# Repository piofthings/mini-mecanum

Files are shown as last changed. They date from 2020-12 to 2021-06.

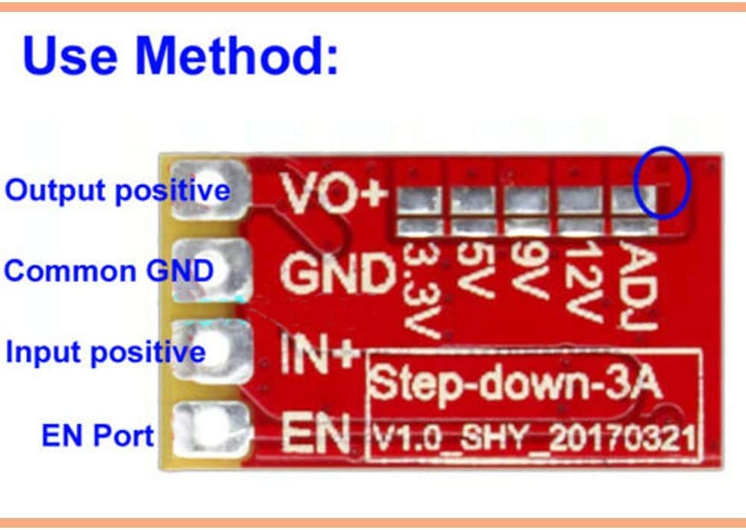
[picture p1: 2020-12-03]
references/powersupply/back-side.jpg

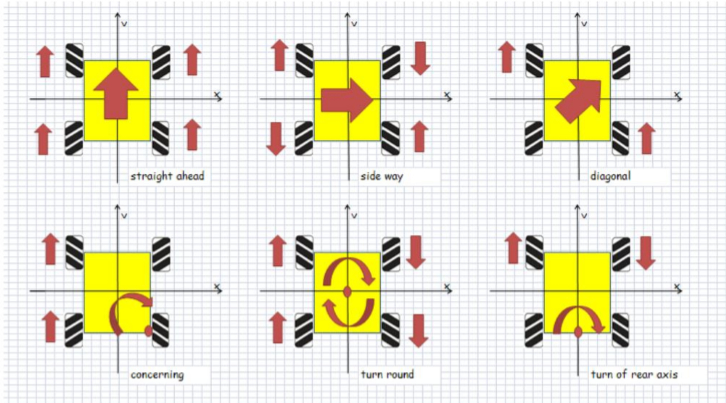
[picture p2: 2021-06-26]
references/mecanum-wheels-direction.jpeg

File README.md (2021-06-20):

# mini-mecanum

Mini Mecanum bot goes to [PiWars at Home 2021](https://piwars.org)

Yes, we couldn't resist and put our names in for [PiWars at Home 2021](https://piwars.org) and now we are in deep trouble.

# Motor Driver using GPIOZero
We are using 2xMDD3A Cytron motor drivers to drive 4 motors independently so we can strafe when we use Mecanum motors. The drivers use PWM signal for forward and backward directions instead of using a PWM and Direction pin.

Looks like the `GPIO Zero` libraries' `Motor` abstraction will work with this driver. So we are using the following Pins on the Pi

| # | Pin | Used | | Wire colour |
| :--- | --- | :--- | :--- | :--- |
| 1. | GPIO 17 (Physical 11) | Left Front | Forward  | Yellow |
| 2. | GPIO 27 (Physical 13) | Left Front | Backward | Blue |
| 3. | GPIO 23 (Phyiscal 16) | Left Rear | Forward  | Yellow |
| 4. | GPIO 24 (Physical 18) | Left Rear | Backward | Blue |
| 5. | GPIO 5 (Phyiscal 29)  | Right Front | Forward  | Yellow |
| 6. | GPIO 6 (Physical 31)  | Right Front | Backward | Blue |
| 7. | GPIO 26 (Phyiscal 37) | Right Rear | Forward  | Yellow |
| 8. | GPIO 16 (Phyiscal 36) | Right Rear | Backward | Blue |
| 9. | GPIO 2 (Physical 3) | I2C SDA | | |
| 10.  | GPIO 3 (Physical 5) | I2C SCL | | |
| 11.  | GPIO 22 (Physical 15) | S (Fish feeder Servo) | | |
| 13.  | Ground (Physical 06)  | UART | | |
| 14.  | GPIO 14 (Physical 08) | UART TX | | |
| 15.  | GPIO 16 (Physical 10) | UART RX | | |
| 16.  | 3v3 (Physical 1) | I2C/UART | | |
| 17.  | 5v (Physical 2) | | | |
| 18.  | GPIO 21 (Physical 40) | Blue Gripper Stop switch  | | |
| 19.  | GPIO 20 (Physical 39) | Red Gripper Stop switch | | |
| 20.  | GPIO 12 (Physical 32) | Green Gripper Stop switch | | |
  
## Used [*] / Unsed [_] (GPIO pins)

| | | | |
| :--- | --- | --- | --- |
| 3v3 Power | 01 [*] | [*] 02 | 5v Power /1 |
| GPIO 2(I2C SDA) | 03 [*] | [_] 04 | 5v Power |
| GPIO 2(I2C SDA) | 05 [*] | [*] 06 | Ground |
| GPIO 4(GPCLK0) | 07 [_] | [*] 08 | GPIO 14 (UART TX) |
| Ground | 09 [_] | [*] 10 | GPIO 15 (UART RX) |
| GPIO 17 | 11 [*] | [_] 12 | GPIO 18 (PCM CLK) |
| GPIO 27 | 13 [*] | [*] 14 | Ground |
| GPIO 22 | 15 [_] | [*] 16 | GPIO 23 |
| 3v3 Power | 17 [_] | [*] 18 | GPIO 24 |
| GPIO 10 (SPI MOSI)  | 19 [_] | [_] 20 | Ground |
| GPIO 9 (SPIO MISO)  | 21 [_] | [_] 22 | GPIO 25 |
| GPIO 11 (SPIO SCLK) | 23 [_] | [*] 24 | GPIO 8 (SPI0 CE0) |
| Ground | 25 [_] | [*] 26 | GPIO 7 (SPI0 CE1) |
| GPIO 0 (EEPROM SDA) | 27 [_] | [*] 28 | GPIO 1 (EEPROM SCL)) |
| GPIO 5 | 29 [*] | [_] 30 | Ground |
| GPIO 6 | 31 [*] | [*] 32 | GPIO 12 (PWM0) |
| GPIO 13 (PWM 1) | 33 [_] | [_] 34 | Ground |
| GPIO 19 (PCM FS) | 35 [_] | [*] 36 | GPIO 16 |
| GPIO 26 | 37 [*] | [*] 38 | GPIO 20 (PCM DIN) |
| Ground 39 | 39 [*] | [*] 40 | GPIO 21 (PCM DOUT) |

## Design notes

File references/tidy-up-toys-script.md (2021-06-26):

#Tidy up toys script

##Starting position
- All at lower most position but staggered Blue and Green lower than Red 
- Arm pinched `p` (angle 0) 
- Shoulders open `j`
- Go Back `s`
- Spin Clockwise `y` until corrected
- Stop `0`
- Go Forward Diagonal right `e`
- Go forward `w`
- Stop

##Grab Blue
- Select Blue `b`
- Release Hand `o`
- Grab hand `l`
- Spin Anticlockwise to face Red `t`
- Forward `w`

##Grab Red
- Select Red `r`
- Release Hand `o` (should swing over Green and Blue)
- Grab Hand  `l`
- Raise Hand `'` (for x seconds, figure out how much is x)
- Strafe right slightly `d` to line up with green
- Go forward `w`

##Grab Green
- Select Green `g`
- Release Hand `o`
- Grab hand    `l`
- Swing In     `h`
- Raise Hand `'` 
(for y seconds, figure out how much is y)
- Strafe left `a`

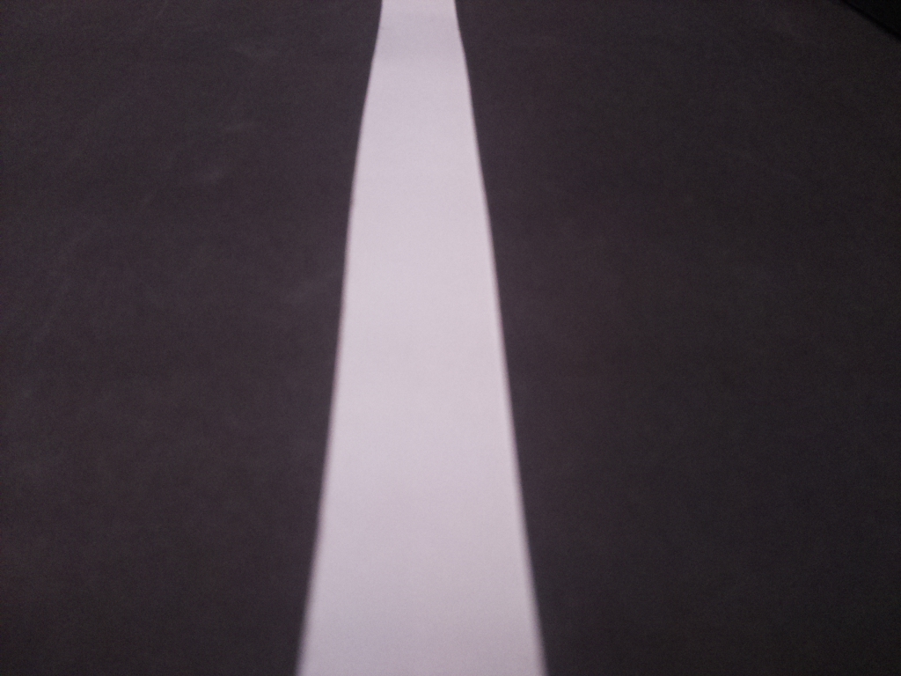
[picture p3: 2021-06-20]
dev/pi/foo.jpg

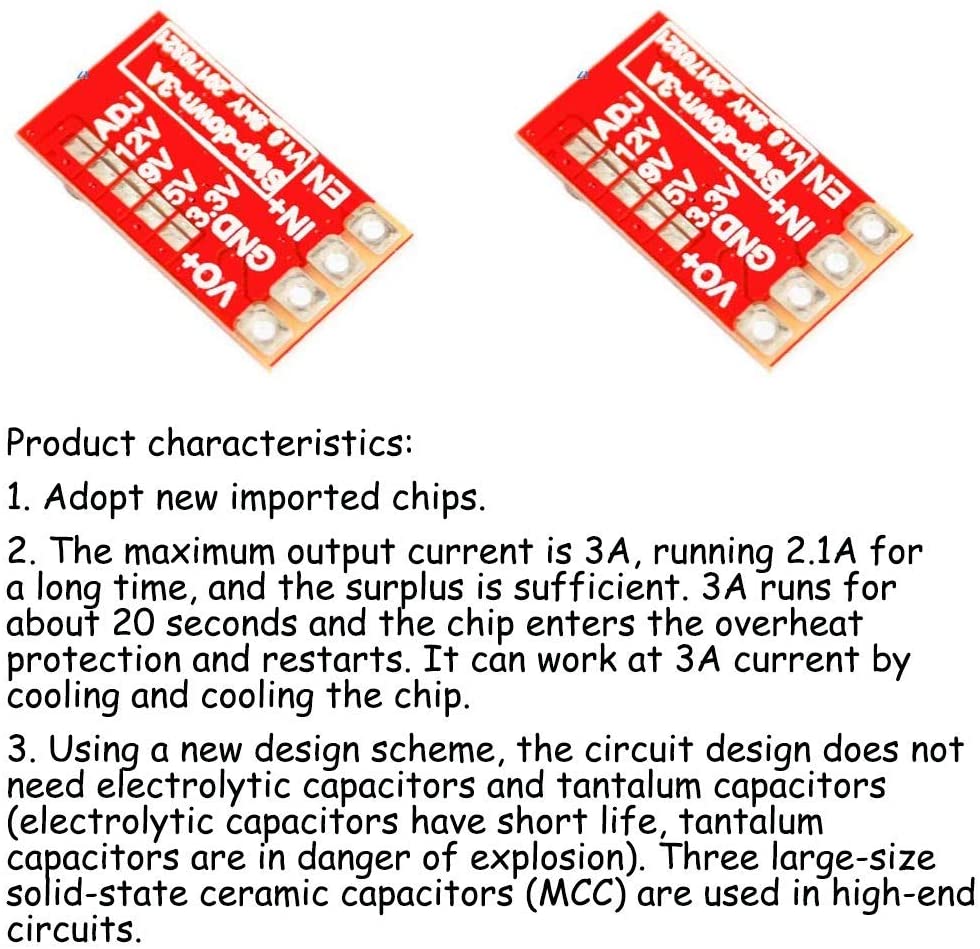
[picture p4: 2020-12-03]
references/powersupply/ratings.jpg

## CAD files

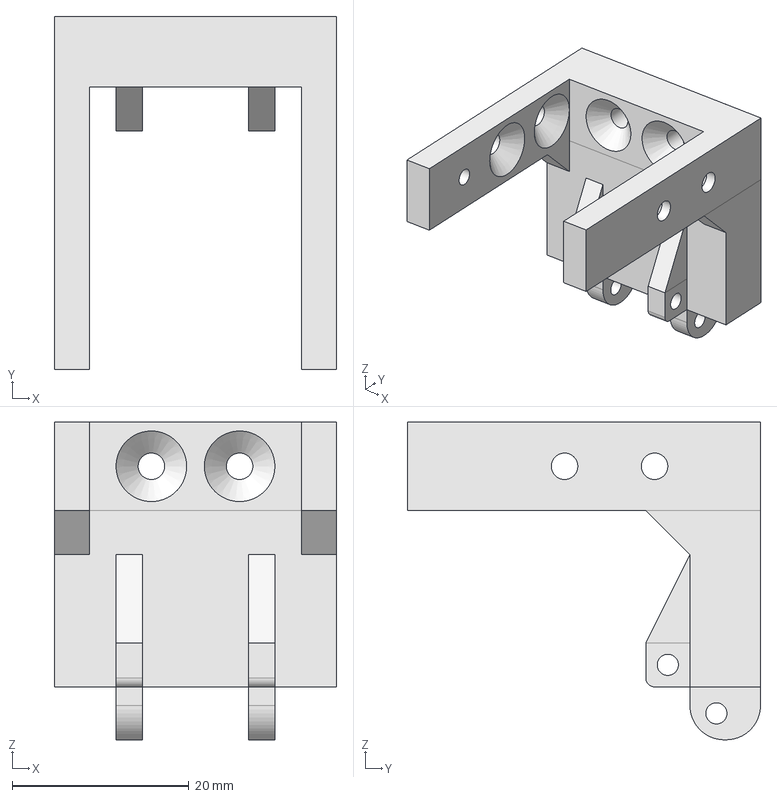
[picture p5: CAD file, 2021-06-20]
CAD/FishFeederLauncher-v2.FCStd
32.0 x 40.0 x 36.0 mm

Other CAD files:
CAD/FishFeederLauncher-v2.stl

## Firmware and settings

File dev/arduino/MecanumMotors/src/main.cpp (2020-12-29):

#include <Arduino.h>
#include <Adafruit_INA260.h>
#include "SoftPWMMotorDriver.h"
#include "main.h"

#define DIR_FORWARD 1;
#define DIR_REVERSE -1;

int currentSpeed = 0;
int currentDirection = DIR_FORWARD;
float max_voltage_mv = 6000.00;
float ina_input_voltage = 0;
float ina_input_current = 0;
float ina_input_power = 0;

// Configure the motor driver.
SoftPwmMotorDriver motor1Rf(PWM_SWPM, 16, 10, max_voltage_mv, 8400.0);   // PWM 1A = Pin 10, PWM 1B = Pin 16.
SoftPwmMotorDriver motor2Rr(PWM_SWPM, 9, 8, max_voltage_mv, 8400.0);     // PWM 2A = Pin 9, PWM 2B = Pin 8.
SoftPwmMotorDriver motor3Lf(PWM_SWPM, 4, 5, max_voltage_mv, 8400.0);     // PWM 1A = Pin 5, PWM 1B = Pin 4.
SoftPwmMotorDriver motor4Lr(PWM_SWPM, 6, 7, max_voltage_mv, 8400.0);     // PWM 2A = Pin 6, PWM 2B = Pin 7.


Adafruit_INA260 ina260 = Adafruit_INA260();

void testMotors() {
  // delay(5000);
  currentSpeed = -255;
  motor1Rf.setSpeed(currentSpeed, ina_input_voltage);   // Motor 1 runs forward at full speed.
  motor3Lf.setSpeed(currentSpeed, ina_input_voltage);   // Motor 1 runs forward at full speed.
  motor2Rr.setSpeed(currentSpeed, ina_input_voltage);   // Motor 2 runs backward at full speed.
  motor4Lr.setSpeed(currentSpeed, ina_input_voltage);   // Motor 2 runs backnward at full speed.
  readPower();
  writeSerialLog();
  delay(5000);

  currentSpeed = 0;
  motor1Rf.setSpeed(currentSpeed, ina_input_voltage);     // Motor 1 stops.
  motor3Lf.setSpeed(currentSpeed, ina_input_voltage);     // Motor 1 runs forward at full speed.
  motor2Rr.setSpeed(currentSpeed, ina_input_voltage);     // Motor 2 stops.
  motor4Lr.setSpeed(currentSpeed, ina_input_voltage);     // Motor 2 runs backward at full speed.
  readPower();
  writeSerialLog();
  delay(5000);

  currentSpeed = 255;
  motor1Rf.setSpeed(currentSpeed, ina_input_voltage);    // Motor 1 runs backward at full speed.
  motor3Lf.setSpeed(currentSpeed, ina_input_voltage);    // Motor 1 runs forward at full speed.
  motor2Rr.setSpeed(currentSpeed, ina_input_voltage);    // Motor 2 runs forward at full speed.
  motor4Lr.setSpeed(currentSpeed, ina_input_voltage);    // Motor 2 runs backward at full speed.
  readPower();
  writeSerialLog();
  delay(5000);

  currentSpeed = 0;
  motor1Rf.setSpeed(currentSpeed, ina_input_voltage);     // Motor 1 stops.
  motor3Lf.setSpeed(currentSpeed, ina_input_voltage);     // Motor 1 runs forward at full speed.
  motor2Rr.setSpeed(currentSpeed, ina_input_voltage);     // Motor 2 stops.
  motor4Lr.setSpeed(currentSpeed, ina_input_voltage);     // Motor 2 runs backward at full speed.
  readPower();
  writeSerialLog();
  delay(5000);
}


void setSpeed(int speed){
  currentSpeed = speed;
  motor1Rf.setSpeed(currentSpeed * currentDirection, ina_input_voltage);
  motor3Lf.setSpeed(currentSpeed * currentDirection, ina_input_voltage);
  motor2Rr.setSpeed(currentSpeed * currentDirection, ina_input_voltage);
  motor4Lr.setSpeed(currentSpeed * currentDirection, ina_input_voltage);
}

void setLRSpeed(int speedLeft, int speedRight){
  motor1Rf.setSpeed(speedRight, ina_input_voltage);
  motor2Rr.setSpeed(speedRight, ina_input_voltage);
  motor3Lf.setSpeed(speedLeft, ina_input_voltage);
  motor4Lr.setSpeed(speedLeft, ina_input_voltage);
}

void setLfLrRfRrSpeed(int speedLeftFront, int speedLeftRear, int speedRightFront, int speedRightRear){
  motor1Rf.setSpeed(speedRightFront, ina_input_voltage);
  motor2Rr.setSpeed(speedRightRear, ina_input_voltage);
  motor3Lf.setSpeed(speedLeftFront, ina_input_voltage);
  motor4Lr.setSpeed(speedLeftRear, ina_input_voltage);
}

void setDirection(int direction){
  currentDirection = direction;
  setSpeed(currentSpeed);
}

String getValue(String data, char separator, int index)
{
  int found = 0;
  int strIndex[] = {0, -1};
  int maxIndex = data.length()-1;

  for(int i=0; i<=maxIndex && found<=index; i++){
    if(data.charAt(i)==separator || i==maxIndex){
        found++;
        strIndex[0] = strIndex[1]+1;
        strIndex[1] = (i == maxIndex) ? i+1 : i;
    }
  }

  return found>index ? data.substring(strIndex[0], strIndex[1]) : "";
}

void receiveEvent() {
  if (Serial1.available() > 0) {
    digitalWrite(LED_BUILTIN, HIGH);   // turn the LED on (HIGH is the voltage level)

    String cInput = Serial1.readStringUntil('\n');
    Serial.println(cInput);
    String c = getValue(cInput, ':', 0);
    String speeds = getValue(cInput, ':', 1);
    int command = c.toInt();
 
    Serial.print("\nCommand: ");
    Serial.println(command);
    Serial.println(speeds);

    switch (command)
    {
      case 1: // Set Speed
      {
        String s = speeds;
        int speed = s.toInt();
        setSpeed(speed);
        Serial.print("\nSpeed: ");
        Serial.println(speed);
        break;
      }
      case 2: // Set Direction
      {
        String d = getValue(speeds, ',', 0);
        int direction = d.toInt();
        Serial.print("\nDirection: ");
        Serial.println(d);
        setDirection(direction);
        break;
      }
      case 3: // Set L-R Speed
      {
        Serial.println("Case 3");
        String sl = getValue(speeds, ',', 0);
        int speedLeft = sl.toInt();
        String sr = getValue(speeds, ',', 1);
        int speedRight = sr.toInt();
        setLRSpeed(speedLeft, speedRight);
        Serial.print("\nSpeed Set: ");
        Serial.print(speedLeft);
        Serial.print(", ");
        Serial.println(speedRight);
        break;
      }
      case 4: // Set Lf-Lr-Rf-Rr Speed
      {
        String slf = getValue(speeds, ',', 0);
        int speedLeftFront = slf.toInt();
        String slr = getValue(speeds, ',', 1);
        int speedLeftRear = slr.toInt();
        String srf = getValue(speeds, ',', 2);
        int speedRightFront = srf.toInt();
        String srr = getValue(speeds, ',', 4);;
        int speedRightRear = srr.toInt();
        setLfLrRfRrSpeed(speedLeftFront,speedLeftRear,speedRightFront,speedRightRear);
        break;
      }
      case 5: // Get Last Power readings
      {
        writeSerialLog();
        Serial1.print(ina_input_current);  
        Serial1.print(", ");  
        Serial1.print(ina_input_voltage);  
        Serial1.print(", ");  
        Serial1.print(ina_input_power);  
        Serial1.print(", ");
        Serial1.println(currentSpeed);  
        break;
      }
    }
  }
  digitalWrite(LED_BUILTIN, LOW);

}

// The setup routine runs once when you press reset.
void setup() {
  pinMode(LED_BUILTIN, OUTPUT);
  Serial1.begin(115200);
  Serial1.println("Starting...");
  if (!ina260.begin()) 
  {    
    Serial.println("Couldn't find INA260 chip");    
    //while (1);  
  }
  Serial.print("Current (mA), ");  
  Serial.print("Bus Voltage (mV), ");  
  Serial.print("Power (mW), ");  
  Serial.print("Current Speed (PWM), ");  
  Serial.println("");
    //testMotors();
}



// The loop routine runs over and over again forever.
void loop() {
  readPower();
  //testMotors();
  //writeSerialLog();
  receiveEvent();
}

void readPower() {
  ina_input_voltage = ina260.readBusVoltage();
  ina_input_current = ina260.readCurrent();
  ina_input_power = ina260.readPower();
}

void writeSerialLog() {
  Serial.print(ina_input_current);  
  Serial.print(", ");  
  Serial.print(ina_input_voltage);  
  Serial.print(", ");  
  Serial.print(ina_input_power);  
  Serial.print(", ");
  Serial.println(currentSpeed);  
}

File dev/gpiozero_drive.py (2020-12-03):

#!/usr/bin/env python3
from gpiozero.pins.pigpio import PiGPIOFactory
from gpiozero import PhaseEnableMotor
from time import sleep


class GpiozeroDrive():
    DIRECTION_FORWARD = 1
    DIRECTION_BACKWARD = 0
    DIRECTION_STRAFELEFT = 3
    DIRECTION_STRAFERIGHT = 4

    __pwmEnablePinWhiteLeftChannel = 12
    __phaseDirPinRedLeftChannel = 5
    __pwmEnablePinWhiteRightChannel = 13
    __phaseDirPinRedRightChannel = 6

    __rightMotors = PhaseEnableMotor(
        phase=__phaseDirPinRedLeftChannel, enable=__pwmEnablePinWhiteLeftChannel, pwm=True)
    __leftMotors = PhaseEnableMotor(
        phase=__phaseDirPinRedRightChannel, enable=__pwmEnablePinWhiteRightChannel, pwm=True)

    __currentSpeed = 0

    def setDirection(self, leftDirection, rightDirection):
        self.__currentLeftDirection = leftDirection
        self.__currentRightDirection = rightDirection

    def moveForward(self, newSpeed):
        if newSpeed >= 0 and newSpeed <= 1:
            self.setDirection(self.DIRECTION_FORWARD, self.DIRECTION_FORWARD)
            self.__rightMotors.forward(speed)
            self.__leftMotors.forward(speed)

    def moveBackward(self, newSpeed):
        if newSpeed >= 0 and newSpeed <= 1:
            self.setSpeed(self.DIRECTION_BACKWARD, self.DIRECTION_BACKWARD)
            self.__rightMotors.backward(speed)
            self.__leftMotors.backward(speed)

    def move(self, directionLeft, directionRight, speedLeft, speedRight):
        self.setDirection(directionLeft, directionRight)
        if (speedLeft >= 0 and speedRight >= 0 and
                speedLeft <= 1 and speedRight <= 1):
            if(directionLeft == self.DIRECTION_FORWARD):
                self.__leftMotors.forward(speedLeft)
            elif(directionLeft == self.DIRECTION_BACKWARD):
                self.__leftMotors.backward(speedLeft)

            if(directionRight == self.DIRECTION_FORWARD):
                self.__rightMotors.forward(speedRight)
            elif(directionRight == self.DIRECTION_BACKWARD):
                self.__rightMotors.backward(speedRight)

    def stop(self):
        self.setSpeed(0)
        self.__rightMotors.forward(0)
        self.__leftMotors.forward(0)

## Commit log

2020-09-06 I2C comms work
2020-10-25 Migrated code to UART
2020-10-31 Trying to move to SoftwarePWM for direction pin only
2020-10-31 Going fully software PWM for all 4 motors
2020-11-01 Software PWM library modified and it works
2020-11-22 Added INA260 based PWM adjustment
2020-11-29 Disabled test sequence on Arduino and basic YUV image capture code
2020-12-03 Sample images and beginnings of image processing
2020-12-07 Restructuring code into packages, Adding tank steering and Mecanum steering base code, smoke_test.py updated to save to a numpy file on exit instead of every frame
2020-12-08 Reformat smokey_test and new sample for camera stream capture
2020-12-08 Reformat camera_stream_capture
2020-12-08 camera_stream_capture updated, but loads of redundant code
2020-12-08 Trimmed out camera_stream_capture
2020-12-12 Brian @usedbytes is a genius! refer to continuous_capture.py for blazing fast framerates on a PiZero
2020-12-13 Captured images named correctly, Api to retrieve battery and power readings
    [smoke_test.py]
2020-12-14 capture playback script and sample files in zip
2020-12-21 Averaging values in single loop, moving speed calculation closer to frame processing
2020-12-28 Removed threading and queues, passing delegates insteads
2020-12-29 Fix (?) L-R speeds for one case and update sim.py to align with non-threaded delegate implementation
2021-01-22 Stuff... updated readme.md and cad files
2021-06-20 Here we go again... not much code has changed, only some documentation updates
    [FishFeederLauncher-v2.FCStd, FishFeederLauncher-v2.stl]
2021-06-20 Uadded plot.py trying to make sense out of sensor data
2021-06-20 Fixed get_battery and updated BNO sample to stuff all readings as csv
    [bn055_sample.py]
2021-06-21 BNO055 is fairly useless without encoders, what was I thinking?
2021-06-22 Added mecanum wheels direction reference image (probably from Vex Robotics
2021-06-26 BNO055 experiments
    [bno1-5.csv, bno1-5.ods]
